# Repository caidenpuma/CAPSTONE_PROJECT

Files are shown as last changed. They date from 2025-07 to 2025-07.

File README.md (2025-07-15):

# CAPSTONE PROJECT

## Overview

This project implements a fully embedded soil monitoring system designed to simplify plant care through real-time environmental sensing and on-device feedback. SoilSense collects and displays data on moisture, temperature, humidity, and light intensity to help plant owners maintain optimal growing conditions. Unlike commercial solutions that rely on mobile app connectivity, SoilSense delivers actionable insights directly via an onboard LCD interface, offering a self-contained, user-friendly experience.

---

## Features

- Real-time sensing of soil moisture, ambient temperature, humidity, and light intensity
- Onboard LCD interface with plant-specific alert logic
- Configurable plant profiles for adaptive threshold monitoring
- LED indicator system for status and fault conditions
- Modular firmware architecture using STM32CubeIDE
- Designed for indoor plants up to 24" in diameter and depth
- Expandable architecture to support automated watering

---

## System Architecture

### Hardware Overview

| Component | Part Number | Function |
|---|---|---|
| Microcontroller | STM32L452RC | ARM Cortex-M4 MCU with low-power capabilities |
| Moisture Sensor | Coliao Capacitive | Soil water content detection |
| Temperature & Humidity Sensor | HDC2010YPAR | Indoor climate sensing |
| Light Sensor | VEML7700 | Ambient light measurement |
| Display | LCD1602 | Local interface for sensor feedback |
| Power Supply | 2x AA Batteries | 3+ months of operation under typical use |

### Functional Block Diagram

```
[Moisture Sensor]       [Light Sensor]        [Temp/Humidity Sensor]
       |                      |                          |
       ---------------------------------------------------
                              |
                     [STM32L452RC MCU]
                              |
     -----------------------------------------------------
     |                    |                      |       |
[LED Indicators]   [LCD1602 Display]     [Push Buttons]   [Battery Pack]
```

---

## Firmware Features

- Sensor drivers implemented using STM32 HAL libraries
- Low-power modes enabled for extended battery life
- Debounced GPIO control for 5-button interface
- LCD feedback includes moisture alerts, temperature warnings, and sunlight recommendations
- Modular codebase organized by sensor/peripheral interface

---

## Display Interface and Controls

| Button | Setup Mode Function | Operation Mode Function |
|---|---|---|
| 1 | Select / Confirm | Open plant selection menu |
| 2 | Calibrate | Clear alerts |
| 3 | Toggle Display | Screen on/off |
| 4 | Back | Return to previous menu |
| 5 | Next | Cycle through sensor readouts or alerts |

---

## PCB and Fabrication

- Designed using KiCad
- Two-layer layout optimized for enclosure integration
- Gerber files and final schematic included in repository
- Moisture sensors located at staggered depths on dual probe legs
- Fully waterproofed casing concept with IP67 design targets

---

## Performance Summary

| Parameter | Value |
|---|---|
| Battery Life | >3 months on 2 AA batteries |
| Update Interval | 10 seconds (default) |
| Minimum Pot Size | 4" diameter and depth |
| Display Visibility | Readable from >3 feet |
| Moisture Sensor Range | 0%–100% volumetric water content (relative) |

---

## Compliance and Design Standards

- IP67 environmental sealing for sensor and electronics protection
- RoHS-compliant components to ensure material safety
- Designed to meet UL guidelines for consumer electronic safety
- Uses non-toxic, corrosion-resistant materials for plant compatibility

---

## Risk Mitigation

| Risk | Strategy |
|---|---|
| Sensor inaccuracy | Early calibration, plant-specific offsets |
| Power constraints | Low-power sleep modes and efficient polling loop |
| Moisture ingress | Enclosure sealing and waterproof connectors |
| Voltage mismatch | Onboard LDOs for 3.3V and 5V regulation |

---

## Getting Started

### Prerequisites

- STM32CubeIDE for firmware development
- ST-Link programmer/debugger
- Access to KiCad or Gerber viewer for PCB inspection
- 2 AA batteries and indoor plant pot for deployment

### Setup Instructions

1. Clone the repository:
   ```bash
   git clone https://github.com/caidenpuma/CAPSTONE_PROJECT.git
   ```

2. Open project file in STM32CubeIDE.

3. Connect the STM32L452RC development board via ST-Link.

4. Build and flash the firmware.

5. Assemble the PCB or use the breadboard prototype to connect sensors and LCD.

6. Insert batteries and deploy on a plant for testing.

---

## Demo and Verification

- Breadboard prototyping completed with working sensor readings
- External STM32F4 board used for software development and timing validation
- Final integrated PCB successfully demonstrated with real-time sensor output
- LCD readouts and LED indicators verified against environmental stimuli

---

## Future Enhancements

- Integration of a closed-loop self-watering system
- Expansion of plant type database with dynamic parameter mapping
- Optional wireless interface for remote notifications
- Enhanced mechanical enclosure for ruggedization

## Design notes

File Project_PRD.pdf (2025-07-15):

## Brown University

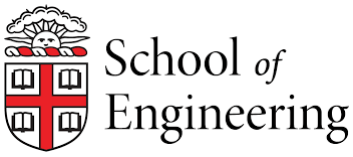
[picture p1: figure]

## ENGN 1650 / AY 24-25 Embedded Microprocessor Design Product Requirements Document

Project Team: Gianna Aiello, Tamar Kreitman, Caiden Puma, Chandler Stevenson

### Project Concept: SoilSense

Building a sensing system for plants to keep them healthy.

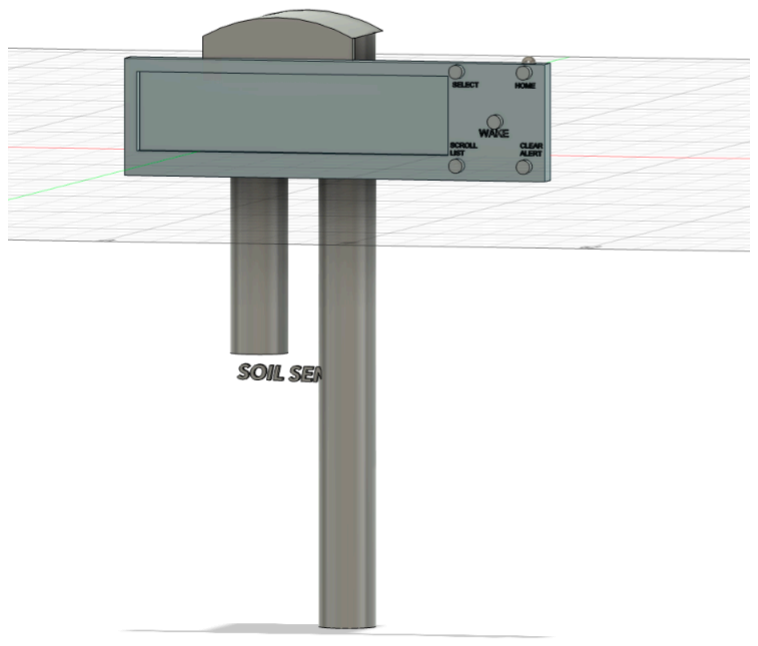
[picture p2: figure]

I. Revision Block
Version | Date
V1 | 10/25/2024
II. | Scope
| SoilSense is aimed at everyday plant owners who often struggle to keep their plants
healthy due to busy schedules or simply not knowing when their plants need attention. It’s also great for anyone who enjoys gardening indoors, people living in apartments or urban areas with limited space, and even tech enthusiasts who want to integrate more smart devices into their homes. The idea is to create a simple, easy-to-use gadget that helps people take better care of their plants by tracking light intensity, moisture, humidity, and temperature. The main goal is to make plant care less of a guessing game and more about giving your plants exactly what they need.

What Is This For?

| ● Market Product: This could definitely become a retail product, considering how many people struggle with plant care and how popular smart home gadgets are becoming. ● Personal or Academic Use: It’s also a solid project for anyone looking to learn about IoT, smart sensors, or even just experimenting with electronics. It could be used in a class project, lab work, or as a research tool. ● Just for Fun: And, of course, it's perfect if you’re just someone who likes tinkering with tech and wants a cool, practical project to build.

Who Would Benefit?

| ● Plant Owners: Obviously, anyone with a houseplant could benefit from this. It’s going to make keeping your plants alive a lot easier. ● Smart Home Fans: This could be a neat addition to a smart home setup, making plant care feel more high-tech and hands-off. ● Students and Learners: It’s also a great educational tool for anyone interested in learning about electronics, IoT, or environmental science.
| In a nutshell, SoilSense aims to make plant care simpler, more efficient, and maybe even
a bit more fun, whether you’re an experienced gardener or someone who just wants their plants to stop dying.

III. | General Description
| Soil Sense is an intuitive soil monitoring device designed specifically for medium-sized
household plants, offering plant enthusiasts an easy and effective way to understand their plant's needs. Unlike many products on the market that require smartphone connectivity, Soil Sense comes with its own built-in display, providing real-time readings of soil moisture, temperature, and nutrient levels right at your fingertips. This means you can instantly check on your plant's health without any extra gadgets or apps, making plant care accessible and stress-free.
| What sets Soil Sense apart is its user-friendly design and precise monitoring capabilities.
Whether you’re a seasoned plant parent or just starting your indoor garden, Soil Sense helps you take the guesswork out of plant care, ensuring your plants receive the right amount of water, warmth, and nutrients to thrive. It’s perfect for those who want to avoid common pitfalls like overwatering or neglecting their plants. Our target audience includes urban dwellers, plant enthusiasts, and anyone looking to maintain a healthy, green space in their home. As we move forward, we plan to expand Soil Sense’s reach, offering a variety of models tailored to different plant types and environments, making it the go-to tool for every indoor gardener.
IV. | Functional Description
| The purpose of SoilSense is to provide low-cost, real time soil monitoring to consumer
plant hobbyists who want to ensure their plants stay healthy. The plants that we service will be predominantly indoor plants whose size does not exceed 24" in diameter and 24" in depth. As the project progresses, these restrictions may change. The following features are essential to the product functionality:
| ● Monitor soil moisture levels and alert user when to water the plant ○ Tell user to water the plant ● Monitor room temperature and humidity and alert the user of poor conditions ○ It’s too hot/cold/humid/dry ● Monitor light intensity and time and alert user of poor conditions ○ Brighter/darker and more time in light/less time in light ● Alert user when it is time to fertilize plant, change soil, and remove dust from plant ● Display these alerts on the LCD screen and allow user to clear alerts with a button ● Attach to side of pot ● LED indicator for alert and charge ● Allow user to select type of plant to properly calculate health parameters ● Display controls:

Button | Setup Mode | Operation Mode
1 | Select/ok | Open plant select
2 | Calibrate | Clear alert
3 | | Screen on/off
4 | Back
5 | Next | Toggle alert

The second phase of the project will involve:
- Incorporate a self-watering system
V. Market Positioning

The market for smart plant health monitoring systems is steadily growing as consumers show increasing interest in urban farming, indoor gardening, and sustainable plant care. Some of the key competitors across the smart plant monitoring market include:
- Click and Grow (https://www.clickandgrow.com/products/the-smart-garden-9-limited-edition) offers an all-inclusive home gardening smart system for $249.95 that features automatic watering, grow lighting, and fertilization. Their companion app allows users to monitor their gardens, receive helpful gardening tips, and see general information about the plant species they are growing. The app also allows users to control the lighting or change the cycle of their garden.
- Sage Sill (https://sageandsill.com/products/smart-plant-water-meter-health-sensor?variant=39659349704901) offers a premium version of their plant monitoring probe with smart app connectivity for $160.97 and a base version with just an LED indicator for $128.99. Sage Sill interfaces with users via the Flower Care app to share data about temperature, light intensity, soil moisture, nutrient levels, and give users access to the Cloud Plant Database. The LED indicator light communicates notification of low moisture, low nutrients, high nutrients, and low battery.
- Flora Pod (https://shop.florasense.com/products/flora-pod) offers an AI plant monitoring system for $63.99. Their Flora App interfaces with the user to communicate data about temperature, moisture, humidity, and light intensity and to provide data-based suggestions. For a premium, users can subscribe to Flora Plus to gain access to unlimited AI photo recognition to identify or diagnose plants.

These products tend to use app connectivity as means of interfacing with the user, leaving room for SoilSense to simplify the process by utilizing an onboard display to communicate directly to the user. SoilSense will fill a few gaps in the current market:

- Most smart gardening solutions are dependent on mobile app monitoring. SoilSense cuts out the need for this, regrounding the user with the plant and encouraging a more hands-on, tactile experience with the product.
- Many of the current products boast complicated app ecosystems or advanced functionality that is not necessary for most applications. SoilSense could appeal to more budget-conscious plant owners who want affordable yet effective solutions.
- Value proposition: SoilSense empowers plant owners to easily monitor their plants’ health by providing feedback through an intuitive, attachable display. SoilSense simplifies care by tracking essential markers such as moisture, temperature, light intensity, and humidity – all at an affordable price.

With entry to mid level pricing, we believe that the set of features and lack of reliance on app connectivity will offer a compelling alternative to other options on the market. A retail price around $50 will stay competitive and remain accessible to plant owners who may be reluctant to spend more. A target cost of production would ideally be under $20 per unit to allow for proper margins and will be heavily driven by:
- Component Cost: Moisture, temperature, and humidity sensors are all relatively inexpensive but components like the battery and a display will drive up costs significantly.
- Enclosure Design: A sturdy and inexpensive enclosure with a reliable mechanism to clip the device onto a pot will constitute a significant part of the manufacturing cost. Ensuring that the probes can be properly positioned without risk of damage will likely drive up costs when designing the final product.

Block Diagram

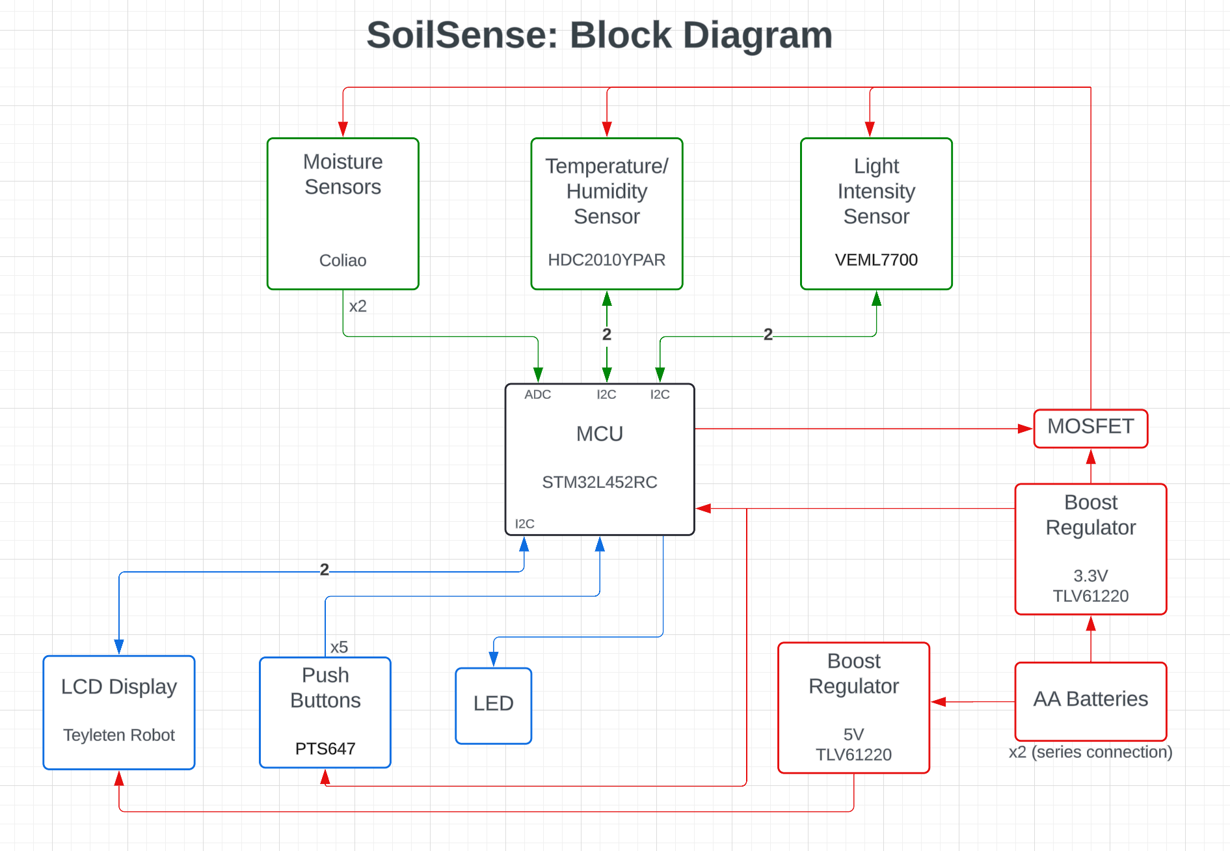
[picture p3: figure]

VI. | Standards Adherence
| SoilSense will adhere to many industry standards through the design process. This will help the product integrate with pre-existing technology like chargers, but meet regulatory requirements that will ensure the safety of users. The following standards are essential to meet: ● Ingress Protection Rating: IP compliance will be upheld given the exposure to water. A rating of IP67 would ensure full dust protection and immersion for 30 minutes at a depth of 1 meter, which would ensure the durability of the product in normal indoor gardening conditions. ● RoHS Compliance: Design will be guided by the RoHS directive to ensure the device is free from harmful chemicals like lead and mercury. It would ensure environmental and user safety and allow the product to be marketed in the EU. ● Underwriters Laboratory Certification: The UL certification would verify that SoilSense meets electronic safety standards. Particularly pertaining to fire hazard, the certification would involve testing for device and power system integrity (like checking short-circuit protection and product durability).

VII. | Industrial Design
| We want a sense of style. The whole case will be waterproof. The two cylinders will look like stakes towards the bottom. They are different lengths because we will house two moisture sensors there at different heights in the soil.

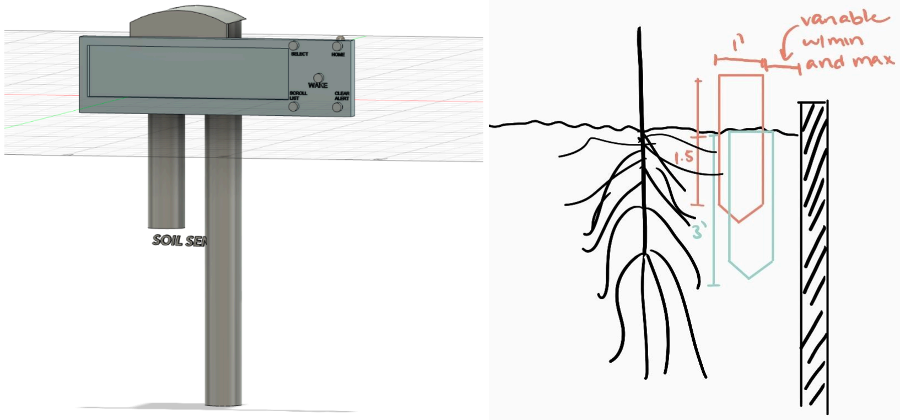
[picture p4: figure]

VIII. | Component Breakdown

Microprocessor:
| ● STM32L452RC available from Digikey
Environmental Sensors:
| ● Light intensity sensor: VEML7700 available from Digikey. ● Temperature and humidity sensor: HDC2010YPAR available from Digikey ● Moisture sensor: Coliao Capacitive Soil Moisture Sensor (Corrosion Resistant)

Display:
| ● Teyleten Robot LCD1602 LCD Display ($2.78)
Power:
| ● Runs on 2 AA batteries supplied by user
IX. | Power Budget

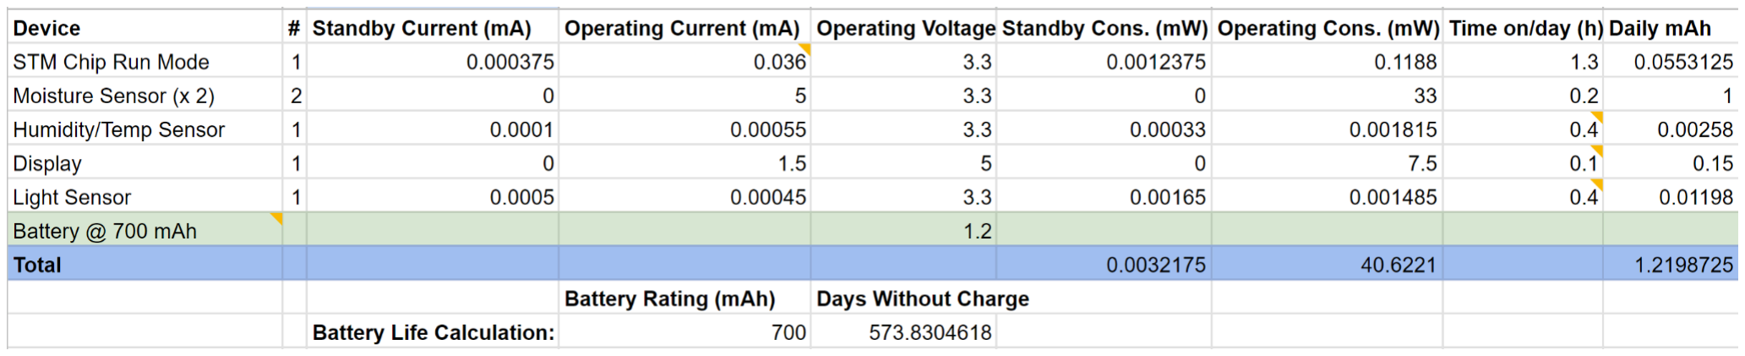
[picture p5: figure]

Fundamental Requirements
- Waterproof: both protecting sensors in the soil and protecting all electronic components from watering
- Readability: Display must be visible from a distance including the alert LED
- Minimum pot diameter: 4 inches
- Minimum pot depth: 4 inches
- Battery must last for at least 3 months without charge
X. Safety Requirements

By prioritizing safety measures, SoilSense will deliver peace of mind to users that the product is not only effective but also safe for everyday use in their homes. To achieve that goal, the following safety conditions will guide the design of the product:
- Fire Safety: Components will meet standards to prevent the possibility of overheat or ignition. Internal circuits should be protected from short circuiting, overheating, and overdrawing current.
- Material Safety: The materials used will be non-toxic and safe for the plants. Under normal operation conditions, the product should not leach chemicals into the soil that could be harmful.
- Water Resistance: Because the product will be used in close proximity to water, electronics will be properly protected from the moisture to avoid failure or hazard. Meeting IP standards could ensure the unit is safe for consumer use.
XI. | Risk Items
| In this early phase, it is important to identify potential risks that could inhibit the product
development timeline. The following are the main risks that need to be addressed before advancing into the design and manufacturing phases:
| ● Sensor Accuracy: Ensuring that the light, moisture, humidity, and temperature sensors are accurate and reliable is essential in collecting data. With uncalibrated sensors, the device may give incorrect recommendations that could harm the plant. Factors like

manufacturing variability, soil type, and general usage will need to be considered. Early testing of the components will mitigate errors and ensure durability of the product.
- Power Management/Battery Life: Some of the components require input voltages of 5 V while others require 3.3 V. Ensuring that the components receive the stable voltages they need will be paramount to the success of the product. Our use case is one in which frequent charging is not ideal, so finding cheap and low power solutions is crucial.
- Weatherproofing: Finding materials to create the product casing will present a significant challenge in the design process. The material will need to endure daily use (especially the buttons) and exposure to moisture, so prototype testing will be necessary to ensure we choose a material that is sufficiently durable but will not drive up production cost. Despite being indoors, the product will also be exposed to sunlight, dust, dirt, and various temperatures. We have to ensure the material used for the casing can withstand these obstacles.
XII. | Schedule
Stage | Tasks | Date Completed | Roles
Ideation | | Completed
Specification | PRD | In Review
| Power Budget | In Review
| Risk Items | Completed
| Team Assembly | Completed
| User Experience | Completed
| Prototypes | In Progress | Gianna
Design | Logic Design | Completed
| Code Development | 11/6
Implementation | Debugging
| Parts Development
| Smoke Tests
| First Demo
| PCB Fabrication | 11/10
Release | Final Report | 12/17
| Data Sheet | 12/17
| Finalized Schematics | 12/17

You are welcome to add other key information about your concept to this specification, but this will cover 90% of what you need and will be a good start! We will continue to refine this document as we go.

Appendix I
“We Build Stuff” (WBS Methodology)

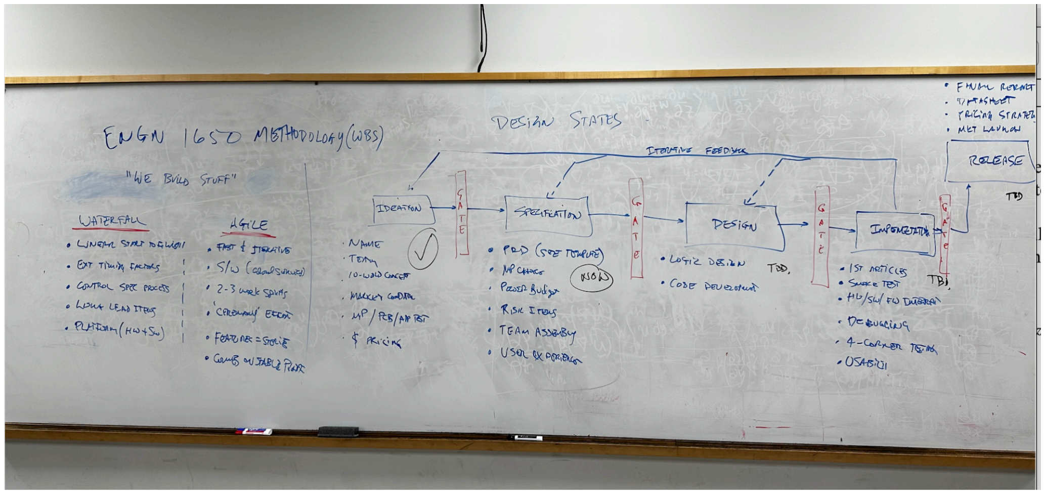
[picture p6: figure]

WBS Product Phases or States

Ideation - concept is vetted with a brief description of what we are trying to achieve. Target market and use. Why it is cool and innovative.

Specification - Create a PRD (Product Requirements Document) to outline all the fundamental requirements for the design. Includes separate prototype efforts to make sure the fundamental risks for the product are identified and vetted out accordingly.

Design - Logic design for the circuitry and all the real-world IO that is associated with the product concept. Includes board layout requirements as well.

Implementation - Build the first articles for the concept. Parts development. PCB fabrication. Smoke tests. First debugging attempts, etc. First demo.

Release - Final documentation of the project. Finalized schematics. BOM.

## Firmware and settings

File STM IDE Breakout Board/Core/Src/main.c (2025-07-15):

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
/* Includes ------------------------------------------------------------------*/
#include "main.h"

/* USER CODE BEGIN Includes */
#include "adc.h"
#include "dht.h"
#include "light_sensor.h"
#include "moisture_sensor.h"
#include "plant_database.h"
#include "setup.h"
#include "temp_rh_sensor.h"
#include "user_interaction.h"
#include "veml7700.h"
#include "liquidcrystal_i2c.h"

/* USER CODE END Includes */

/* USER CODE BEGIN PD */
#define VEML7700_I2C_ADDRESS    0x10

/* USER CODE END PD */

ADC_HandleTypeDef hadc1;

I2C_HandleTypeDef hi2c1;
I2C_HandleTypeDef hi2c3;

RTC_HandleTypeDef hrtc;

TIM_HandleTypeDef htim10;

UART_HandleTypeDef huart2;

/* USER CODE BEGIN PV */
veml7700 veml;

/* USER CODE END PV */

void SystemClock_Config(void);
static void MX_GPIO_Init(void);
static void MX_USART2_UART_Init(void);
static void MX_ADC1_Init(void);
static void MX_I2C1_Init(void);
static void MX_TIM10_Init(void);
static void MX_RTC_Init(void);
static void MX_I2C3_Init(void);
/**
  * @brief  The application entry point.
  * @retval int
  */
int main(void)
{

  /* MCU Configuration--------------------------------------------------------*/

  /* Reset of all peripherals, Initializes the Flash interface and the Systick. */
  HAL_Init();

  /* Configure the system clock */
  SystemClock_Config();

  /* Initialize all configured peripherals */
  MX_GPIO_Init();
  MX_USART2_UART_Init();
  MX_ADC1_Init();
  MX_I2C1_Init();
  MX_TIM10_Init();
  MX_RTC_Init();
  MX_I2C3_Init();
  /* USER CODE BEGIN 2 */
  HD44780_Init(2);
  veml7700_init(&veml, &hi2c3, VEML7700_I2C_ADDRESS);


  /* USER CODE END 2 */

  /* Infinite loop */
  /* USER CODE BEGIN WHILE */
  while (1)
  {
	  // CHECK SETUP
	  if (user_selected_plant.high_temp==0)  // check if plant has been selected
	  {
		  select_plant();
	  }
	  if (calibrated_wet_level==0) // check if moisture level calibrated
	  {
		  calibrate_moisture(hadc1);
	  }
	  if (pot_depth==0) // check if pot depth has been selected
	  {
		  select_pot_depth();
	  }
	  if(*flags[1]==1) // user-initiated recalibration
	  {
		  clear_flags();
		  change_setup(hadc1);
	  }


	  // OPERATION
	  if (*flags[0])  // if RTC IRQ set (every 1 minute for demo TODO: make sure that's enough time)
	  {
		  //HAL_GPIO_WritePin(GPIOC, GPIO_PIN_13, GPIO_PIN_SET); // enable pullup for sensor I2C

		  // TEMP/RH
		  //HAL_GPIO_WritePin(GPIOB, GPIO_PIN_15, GPIO_PIN_SET);
		  HAL_Delay(10);
		  get_temp_and_rh_value();
		  check_temp();
		  check_rh();
		  //HAL_GPIO_WritePin(GPIOB, GPIO_PIN_15, GPIO_PIN_RESET);

		  // LIGHT
		  // Note: for demo just checking light level on every reading
		  //HAL_GPIO_WritePin(GPIOC, GPIO_PIN_14, GPIO_PIN_SET);
		  get_light_value(veml);
		  check_light_intensity();
		  if(light_24h_counter==5) {light_24h_counter=0;}
		  else {light_24h_counter++;}
		  //HAL_GPIO_WritePin(GPIOC, GPIO_PIN_13, GPIO_PIN_RESET); // disable pullup for sensor I2C

		  // MOISTURE
		  // Note: for demo checking on every RTC trigger
		  // enable power to moisture sensors
		  //HAL_GPIO_WritePin(GPIOB, GPIO_PIN_13, GPIO_PIN_SET);
		  //HAL_GPIO_WritePin(GPIOB, GPIO_PIN_14, GPIO_PIN_SET);
		  get_moisture_value(hadc1);
		  check_moisture_level();
		  // disable power to moisture sensors
		  //HAL_GPIO_WritePin(GPIOB, GPIO_PIN_13, GPIO_PIN_RESET);
		  //HAL_GPIO_WritePin(GPIOB, GPIO_PIN_14, GPIO_PIN_RESET);
	  }

	  if(*flags[3]==1) // turn screen on/off
	  {
		  clear_flags();
		  display_toggle();
	  }

	  if (display_is_on)
	  {
		  HAL_GPIO_WritePin(GPIOA, GPIO_PIN_5, GPIO_PIN_RESET);
		  show_alerts();
	  }
	  else if (count_alerts()!=0)
	  {
		  HAL_GPIO_WritePin(GPIOA, GPIO_PIN_5, GPIO_PIN_SET);
	  }
	  else {
		  HAL_GPIO_WritePin(GPIOA, GPIO_PIN_5, GPIO_PIN_RESET);
	  }

    /* USER CODE END WHILE */

    /* USER CODE BEGIN 3 */
  }
  /* USER CODE END 3 */
}

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
/* USER CODE BEGIN 4 */
void HAL_GPIO_EXTI_Callback(uint16_t GPIO_Pin)

{
	static uint32_t last_interrupt_time = 0;
	uint32_t current_time = HAL_GetTick();
	if (current_time - last_interrupt_time < 200)
	{
		return;
	}
	last_interrupt_time = current_time;

	if(GPIO_Pin == GPIO_PIN_8)
	{
		HAL_GPIO_TogglePin(LD2_GPIO_Port, LD2_Pin);
		toggle_flag(1);
	}
	else if(GPIO_Pin == GPIO_PIN_10)
	{
		HAL_GPIO_TogglePin(LD2_GPIO_Port, LD2_Pin);
		toggle_flag(2);
	}
	else if(GPIO_Pin == GPIO_PIN_4)
	{
		HAL_GPIO_TogglePin(LD2_GPIO_Port, LD2_Pin);
		toggle_flag(3);
	}
	else if(GPIO_Pin == GPIO_PIN_5)
	{
		HAL_GPIO_TogglePin(LD2_GPIO_Port, LD2_Pin);
		toggle_flag(4);
	}
}


void HAL_RTC_AlarmAEventCallback(RTC_HandleTypeDef *hrtc) {
  RTC_AlarmTypeDef sAlarm;
  HAL_RTC_GetAlarm(hrtc,&sAlarm,RTC_ALARM_A,FORMAT_BIN);
  if(sAlarm.AlarmTime.Minutes>58) {
    sAlarm.AlarmTime.Minutes=0;
  }else{
    sAlarm.AlarmTime.Minutes=sAlarm.AlarmTime.Minutes+1;
  }
    while(HAL_RTC_SetAlarm_IT(hrtc, &sAlarm, FORMAT_BIN)!=HAL_OK){}
    toggle_flag(0);
}

/* USER CODE END 4 */
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


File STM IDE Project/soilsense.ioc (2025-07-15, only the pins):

Mcu.UserName=STM32L452RCTx
PA0.Signal=UART4_TX
PA1.Signal=UART4_RX
PA10.Signal=GPXTI10
PA2.Signal=GPIO_Input
PA3.Signal=GPIO_Input
PA4.Signal=GPIO_Input
PA7.Signal=I2C3_SCL
PA8.Signal=GPIO_Output
PB0.Signal=GPIO_Output
PB1.Signal=GPXTI1
PB10.Signal=I2C4_SCL
PB11.Signal=I2C4_SDA
PB12.Signal=GPIO_Output
PB13.Signal=GPIO_Output
PB14.Signal=GPIO_Output
PB15.Signal=GPIO_Output
PB2.Signal=GPXTI2
PB6.Signal=GPIO_Output
PC0.Signal=ADCx_IN1
PC1.Signal=ADCx_IN2
PC12.Signal=GPIO_Output
PC13.Signal=GPIO_Output
PC2.Signal=ADCx_IN3
PC3.Signal=ADCx_IN4
PC6.Signal=GPXTI6
PC7.Signal=GPIO_Input
PC8.Signal=GPIO_Output

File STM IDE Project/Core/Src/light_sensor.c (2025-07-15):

/* SoilSense
 * Functions for operation of light sensor VEML7700
 */

#include "stm32l4xx_hal.h"
#include "user_interaction.h"
#include "setup.h"
#include "veml7700.h"
#include <stdint.h>
#include <math.h>

#include "light_sensor.h"

uint32_t light_int_24_hrs[144]; 		// stores 24 hours worth of 6 light intensity readings/hour
uint32_t daily_optimal_time[3]; 		// stores last 3 days of time in optimal light, in minutes
uint32_t daily_max_ints[3]; 			// stores last 3 days of max hourly intensities, in lux

uint32_t light_24h_counter = 0;			// GLOBAL: 0-143 for light_int_24_hrs, value updated in main
uint32_t light_3day_counter = 0;		// GLOBAL: 0-2 for both daily_x arrays, value updated in main

/* Converts VEML7700 output to lux value (formula in application note)
 * Parameters:
 * - veml_raw: raw output of VEML7700 I2C read
 * Returns: lux value corresponding to input
 * Note: correction formula output doesn't match what is in datasheet but does match exactly with calculator
 */
static uint32_t convert_to_lux(uint16_t veml_raw){
	uint32_t lux;
	// for ALS gain = 1/4 and integration time = 100ms
	lux = veml_raw * 0.2688;
	if(lux>1000){ // correction formula
		double lux_a = pow(6.0135,-13);
		double lux_b = pow(-9.3924,-9);
		double lux_c = pow(8.1488,-5);
		double lux_d = 1.0023;
		lux = lux_a*pow((double)lux,4) + lux_b*pow((double)lux,3) + lux_c*pow((double)lux,2) + lux_d*lux;
	}
	return lux;
}

/* Reads values of light sensor
 * Parameters:
 * - veml: pointer to initialized veml
 * Returns: raw ADC reading
 */
static uint16_t light_i2c_read(veml7700 *veml){
	uint16_t als_raw;
	veml7700_power_on(veml);
	// according to datasheet should need delay of 2.5 ms after wakeup
	HAL_Delay(115); // experimentally: doesn't work at 112, does work at 115
	als_raw = veml7700_read_als(veml);
	// turn off to save power
	veml7700_shutdown(veml);
	return als_raw;

}

/* Takes light level category of plant and outputs high end of light range
 * Parameters:
 * - light_level: light level parameter of user's selected plant
 * Returns: int corresponding to upper bound of acceptable lux range
 */
static uint32_t light_level_to_lux_high(uint8_t light_level){
    switch(light_level) {
        case 1:
            return 1076; // low light
            break;
        case 2:
            return 5382; // medium light
            break;
        case 3:
            return 10764; // bright indirect light
            break;
        case 4:
            return 99999; // direct light
            break;
        default:
        	return 0;
        	break;
    }
}

/* Takes light level category of plant and outputs low end of light range
 * Parameters:
 * - light_level: light level parameter of user's selected plant
 * Returns: int corresponding to lower bound of acceptable lux range
 */
static uint32_t light_level_to_lux_low(uint8_t light_level){
    switch(light_level) {
        case 1:
            return 270; // low light
            break;
        case 2:
            return 1076; // medium light
            break;
        case 3:
            return 5382; // bright indirect light
            break;
        case 4:
            return 10750; // direct light
            break;
        default:
        	return 0;
        	break;
    }
}

/* Calculates the daily time spent in optimal light range
 * Parameters:
 * - light_level: light level parameter of user's selected plant
 */
void mins_in_optimal_light(int light_level){
	uint32_t optimal_time, high, low;
	optimal_time = 0;
	high = light_level_to_lux_high(light_level);
	low = light_level_to_lux_low(light_level);
    for(int i=0; i<144; i++){
    	uint32_t light = light_int_24_hrs[i];
        if((light<high) && (light>low)){
            optimal_time++;
        }
    }
    daily_optimal_time[light_3day_counter]=optimal_time*10;
}

/* Calculates average daily time in optimal light
 * Returns: average daily time in optimal light range over last 3 days in minutes
 */
static uint32_t average_optimal_light_time(){
	uint32_t sum, avg;
	sum = 0;
    for(int i=0; i<3; i++){
        sum += daily_optimal_time[i];
    }
    avg = sum/3;
    return avg;
}

/* Calculates average max light intensity in optimal light range
 * Returns: average max light intensity in optimal light range over last 3 days, in lux
 */
static uint32_t average_optimal_light_ints(){
	uint32_t sum, avg;
	sum = 0;
    for(int i=0; i<3; i++){
        sum += daily_max_ints[i];
    }
    avg = sum/3;
    return avg;
}

/* Takes 5 readings of light meter 2 seconds apart and averages them to get value
 * Stores values in array light_int_24_hrs
 */
void get_light_value(veml7700 *veml){
    uint32_t sum, avg, lux;
    uint16_t reading;
    sum = 0;
    for(int i=0; i<5; i++) {
        reading = light_i2c_read(veml);
        lux = convert_to_lux(reading);
        sum += lux;
        HAL_Delay(2000);
    }
    avg = sum/5;
    light_int_24_hrs[light_24h_counter] = avg;
}

/* Calculates peak average hourly light intensity of one day by
 * checking if current hourly average higher than previous max
 */
void calc_high_intensity(){
	uint32_t sum, intensity, last_hour_intensity;
	sum=0;
    static uint32_t max_hourly_intensity = 0;
    // average last hour of intensities
    if(light_24h_counter>4) { // wait for at least one hour of readings
        for(int i=0; i<6; i++){
            intensity = light_int_24_hrs[light_24h_counter-i];
            sum += intensity;
        }
        last_hour_intensity = sum/6;
        // if higher than current average update as new max
        if (last_hour_intensity > max_hourly_intensity){
            max_hourly_intensity = last_hour_intensity;
        }
    }
    if (light_24h_counter==143){ // at end of day store daily max and reset max
        daily_max_ints[light_3day_counter] = max_hourly_intensity;
        max_hourly_intensity = 0;
    }
}

/* Check if 3-day average light intensity in acceptable range
 */
void check_light_intensity(){
	uint32_t max_ok_light, min_ok_light, avg_intensity;
	max_ok_light = light_level_to_lux_high(user_selected_plant.light_level);
	min_ok_light = light_level_to_lux_low(user_selected_plant.light_level);
	avg_intensity = average_optimal_light_ints();
    if (avg_intensity>max_ok_light){ // too bright
        update_alert(3,1);
    } else {
    	update_alert(3,0);
    }
    if (avg_intensity<min_ok_light){ // too dark
        update_alert(2,1);
    }
    else {
        update_alert(2,0);
    }
}

/* Check if 3-day average light time in acceptable range (within 1 hr of ideal)
 */
void check_light_time(){
	uint32_t measured_light_mins, ideal_light_mins;
	measured_light_mins = average_optimal_light_time();
	ideal_light_mins = user_selected_plant.light_time * 60;
    if (measured_light_mins<(ideal_light_mins-60)){ // not enough light
        update_alert(0,1);
    }
    else{
    	update_alert(0,0);
    }
    if (measured_light_mins>(ideal_light_mins+60)){ // too much light
        update_alert(1,1);
    }
    else {
        update_alert(1,0);
    }
}

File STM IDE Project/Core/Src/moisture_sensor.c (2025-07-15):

/* SoilSense
 * Functions for operation of moisture sensor
 */

#include "stm32l4xx_hal.h"
#include "stm32l4xx_hal_adc.h"
#include "adc.h"
#include "setup.h"
#include "user_interaction.h"
#include <stdint.h>

#include "moisture_sensor.h"

uint16_t moisture_sensor_readings[2];	// stores last value of averaged raw ADC readings for the two moisture sensors

uint16_t moisture_12h_counter = 0;		// GLOBAL: 0-71 to time moisture readings, value updated in main

/* Converts raw ADC value to a percent soil moisture
 * Parameters:
 * - adc_raw: corresponds to raw ADC output
 * Returns: % soil moisture reading from moisture sensor
 */
static uint16_t adc_to_pct_moisture(uint16_t adc_raw){
	uint16_t percent_moisture;
	uint32_t step, mvolt;
	mvolt = adc_raw*1000*3.3/4095;
	if(mvolt>DRY_ADC_LEVEL){
		return 100;
	} else if (mvolt<calibrated_wet_level){
		return 0;
	} else {
		step = DRY_ADC_LEVEL-calibrated_wet_level;
		percent_moisture = (mvolt-calibrated_wet_level)*100/step;
		return percent_moisture;
	}
}

/* Estimates the moisture at a given soil depth
 * Parameters:
 * - pct_depth: ranges from 0 (top) to 1 (bottom), fraction of pot depth where
 *              critical depth is found
 * - ms1: reading from higher (0"-2.5") moisture sensor, in raw ADC reading
 * - ms2: reading from lower (1"-3.5") moisture sensor, in raw ADC reading
 * Returns: estimate of moisture at given soil depth, in % moisture
 */
static uint16_t moisture_at_depth(float pct_depth, uint16_t ms1_raw, uint16_t ms2_raw){
	uint16_t moisture_at_cd;
	float crit_depth, k;
	uint32_t x = 2.5*(0.7*ms1_raw-0.3*ms2_raw);
	uint32_t y = (ms1_raw+ms2_raw)/2;
	uint32_t z = 2.5*(0.7*ms2_raw-0.3*ms1_raw);
	int diff = x-y;
    crit_depth = pct_depth*pot_depth;
    if (crit_depth>3.5) { // have to extrapolate
        k = crit_depth - 3.5;
        moisture_at_cd = z-k*diff;
    }
    else if(crit_depth>2.5) { // critical depth is in z range
        moisture_at_cd = z;
    }
    else if(crit_depth>1) { // critical depth is in y range
        moisture_at_cd = y;
    }
    else { // critical depth is in x range
        moisture_at_cd = x;
    }
    return adc_to_pct_moisture(moisture_at_cd);
}

/* Store averaged raw ADC values from 5 reads in array moisture_sensor_readings
 * Parameters:
 * - adc: initialized ADC
 * Returns: averaged raw ADC value for higher moisture sensor
 * TODO: update return value (extra parameter to chose which? don't return anything?)
 */
uint16_t get_moisture_value(ADC_HandleTypeDef adc){
    uint32_t sum1, sum2;
    uint16_t s1, s2, avg1, avg2;
    sum1 = 0; sum2 = 0;
    for(int i=0; i<5; i++) {
    	s1 = adc_channel_conv(1, adc);
        sum1 += s1;
        s2 = adc_channel_conv(3, adc);
        sum2 += s2;
        HAL_Delay(200);
    }
    avg1 = sum1/5;
    avg2 = sum2/5;

    moisture_sensor_readings[0] = avg1;
    moisture_sensor_readings[1] = avg2;

    return avg1;
}

/* Checks if plant needs watering based on pot height and plant type
 * (algorithm is still a work in progress)
 */
void check_moisture_level(){
	uint16_t high_moisture, low_moisture, cd_moisture;
	uint16_t ms1_raw, ms2_raw;
	float pct_depth;
	ms1_raw = moisture_sensor_readings[0];
	ms2_raw = moisture_sensor_readings[1];
	high_moisture = user_selected_plant.high_moisture;
	low_moisture = user_selected_plant.low_moisture;
    pct_depth = 0;
    if (high_moisture<21){ // low moisture plants
        pct_depth = 0.90;
    }
    else if (high_moisture<61){ // medium moisture plants
        pct_depth = 0.33;
    }
    else { // high moisture plants
        pct_depth = 0.15;
    }
    cd_moisture = moisture_at_depth(pct_depth,ms1_raw,ms2_raw);
    if (cd_moisture<low_moisture){
        update_alert(8,1);
    }
    else {
        update_alert(8,0); // clears alert if in proper range
    }
}

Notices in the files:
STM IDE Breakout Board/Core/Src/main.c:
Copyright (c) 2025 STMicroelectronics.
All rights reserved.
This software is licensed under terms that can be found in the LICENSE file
